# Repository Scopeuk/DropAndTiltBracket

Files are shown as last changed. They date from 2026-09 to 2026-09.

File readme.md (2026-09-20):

# Drop and tilt bracket
This is a quick and basic openscad model, it's small and relatively quick to print. All parts are printed.  
The arm will rotate from vertical to near horizonal with the top of the bracket remaining inline with the track.  
The bracket can rotate in either direction.  

## Exploded Diagram
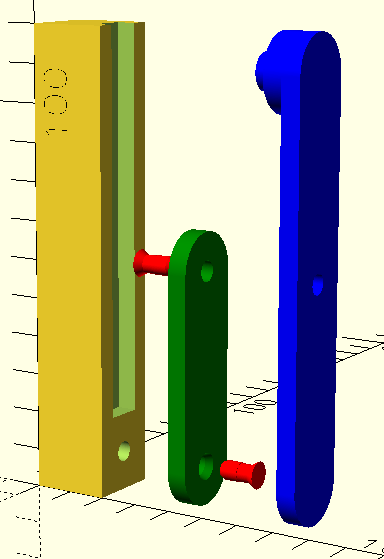
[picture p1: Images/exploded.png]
Exploded diagram


## Printing
All parts in the diagram should be printed once.
This should give you:  
two pins (red)  
one rotating arm (green)  
one sliding arm (blue)  
one support (yellow)  

## Assembly instructions
1. insert one pin from each side of the rotating arm (make sure to insert the pin from the side with the beveled edge)
2. press one of the pins (it doesn't matter which) into the middle hole on the sliding arm
3. sit the large pin of the sliding arm into the track on the support, locate the other pin above the hole at the base of the track and push it firmly home. The arm can be in any position whilst this is done.

## Known Problems
* pinned joints can be stiff to install, I used a small trigger clamp to push them home

The pinned joints provide constraint and the ability to rotate

## Where to find STLs?
STL files are generated using github actions to make sure they are up to date with the repo
visit [Actions](https://github.com/Scopeuk/DropAndTiltBracket/actions) and grab the latest build

Select the download button in the artefacts section

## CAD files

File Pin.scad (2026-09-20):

// create a pin to constrain the part
//should print sat on the wide end without difficulty
// should have a narrower "bearing surface" for the moveing part
//should end in a slightly wider profile to lock in
// use a wedge profile such that joint preload can be controlled by adjusting the insertion distance slightly

pinDia = 5;
pinClearence = 0.3;
//reduced tolerence for parts printed in ideal orientation
pinClearenceVert = 0.2;

$fs = 0.1;
$sa = 1;
//cone is part of the bearing
module pin(
matingLength = 5,
bearingLength = 5,
coneLength = 2,
coneOuterDia = 7,
pinDia = pinDia,
bearingDelta = pinClearence,
chamferLength = 1,
chamferStep = 1
){
assert(bearingLength>coneLength, "bearing length must be longer than cone length");
translate([0,0,-(matingLength+bearingLength)]) {
    //chamfer to make locating into hole easier
    cylinder(d1=pinDia-chamferStep,d2 = pinDia,h= chamferLength);
    //mating section is a fixed length plug
    translate([0,0,chamferLength-0.001]) cylinder(d=pinDia,h= matingLength-chamferLength);
    //bearing shaft is full length inside part
    translate([0,0,chamferLength]) cylinder(d=pinDia-bearingDelta,h= matingLength+bearingLength-chamferLength);
    //coneic mating surface
    translate([0,0,(matingLength+bearingLength)-coneLength]) cylinder(d1=pinDia-bearingDelta,d2 = coneOuterDia,h= coneLength);
    }
}

module pinClearence(
Length = 10,
pinDia = pinDia,
bearingDelta = pinClearence*1.5,
coneLength = 2,
coneOuterDia = 7,
overHead = 0.1
){
assert(Length>coneLength, "bearing length must be longer than cone length");
translate([0,0,-(Length)]) {
    //clear to the pin diamter throughout
    cylinder(d=pinDia+bearingDelta,h=Length);
    //coneic mating surface
    translate([0,0,(Length)-coneLength]) cylinder(d1=pinDia+bearingDelta,d2 = coneOuterDia,h= coneLength);
    translate([0,0,Length-0.01]) cylinder(d=coneOuterDia,h=overHead);
    }
}

module pinMate(Length = 10, pinClearence = pinClearence, overHead = 0.1){

    translate([0,0,-Length]) cylinder(d=pinDia+pinClearence,h=Length+overHead);

}
rotate([180,0,0]){
//translate([-10,0,0]) pinClearence();
translate([ 0,0,0]) pin();
//translate([ 10,0,0]) pinMate();
}

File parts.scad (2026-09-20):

use <Pin.scad>
$fs=0.1;
$fa=1;


screenHeight = 100;

standardDepth = 20;
supportWidth = 20;
rotArmWidth = 5;
// full size cutout for now to allow on axis positioning
rotArmDepth = standardDepth;
rotArmPivotSep = screenHeight/2;
rotArmLength = rotArmPivotSep+rotArmDepth;
clearence = 0.5;

trackDepth = 5;
trackWidth = 10;

//size of the notch in the track for the center point to go home
notchHeight = 12;
//base assembly
module base(){
    partHeight = screenHeight+rotArmDepth;
    difference(){
    cube([supportWidth,standardDepth,partHeight]);
	//interface to rot arm
    translate([supportWidth,standardDepth/2,rotArmDepth/2]) rotate([0,90,0]) pinMate();
    //track, simple pin
    translate([supportWidth-trackDepth,standardDepth/2-trackWidth/2,rotArmDepth]) cube([trackDepth,trackWidth,screenHeight]);
    }
    
    

}

module arm(){
    translate([rotArmWidth,standardDepth/2,rotArmDepth/2]) rotate([0,-90,0]) difference() 
    {
        hull(){
            cylinder(h=rotArmWidth,d=rotArmDepth);
            translate([rotArmPivotSep,0,0]) cylinder(h=rotArmWidth,d=rotArmDepth);
        }
        
        translate([0,0,0]) rotate([0,-180,0]) pinClearence();
        translate([rotArmPivotSep,0,rotArmWidth]) pinClearence();
    }
}

module slidingComponent(){
    PartDepth = 10-rotArmWidth;
    translate([supportWidth+PartDepth+rotArmWidth+clearence*2,standardDepth/2,rotArmDepth/2]) rotate([0,-90,0]){
    //for now this is a place holder, on something proper this would be a singel part fo the screen
	difference(){
		hull(){
			cylinder(d=standardDepth,h=PartDepth);
			translate([screenHeight,0,0]) cylinder(d=standardDepth,h=PartDepth);
		}
        translate([screenHeight/2,0,PartDepth]) pinMate();
	}
    //slidePin, two parts, wide sliding, narrow into slot
    translate([screenHeight,0,0]) {
		cylinder(d=trackWidth-clearence, h = trackDepth+PartDepth+rotArmWidth);
		cylinder(d=standardDepth,h=PartDepth+rotArmWidth);
	}
    }
}

module assembly(){
base();
color("green") translate([supportWidth + clearence ,0,0]) arm();
color("blue") slidingComponent();
color("red") translate([supportWidth+clearence+rotArmWidth,standardDepth/2+clearence ,rotArmDepth/2]) rotate([0,90,0]) pin();
color("red") translate([supportWidth + clearence,standardDepth/2+clearence,rotArmDepth/2+rotArmPivotSep])rotate([0,-90,0]) pin();

}

module exploded(){
base();
translate([40,0,0]) color("green") arm();
translate([45,0,0])color("blue") slidingComponent();
translate([25,0,0]) color("red") translate([0,standardDepth/2+clearence,rotArmDepth/2+rotArmPivotSep])rotate([0,-90,0]) pin();
translate([60,0,0]) color("red") translate([0,standardDepth/2+clearence,rotArmDepth/2]) rotate([0,90,0]) pin();
}

//assembly();
exploded();

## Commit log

2026-09-20 Version 1 (pivot arm to off side)
    [Pin.scad, parts.scad]
2026-09-20 Update model to place the rotating arm between the support and the moving part and fix a typo
    [parts.scad]
